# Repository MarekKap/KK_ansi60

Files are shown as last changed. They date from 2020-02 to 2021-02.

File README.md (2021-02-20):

# KK_ansi60
60% mechanical keyboard

KK_ansi60 keyboard is inspired by [GH60 open source keyboard](https://github.com/komar007/gh60).
Case and mounting plate are made from one piece of aluminium alloy. This feature allows very
solid and compact design. On the other hand only ane switch layout is supported.
Keyboard support TMK firmware, so everything is open source and customizable. On default there
are two base layers. Active layer is indicated with LED under FN1 or FN2 key.

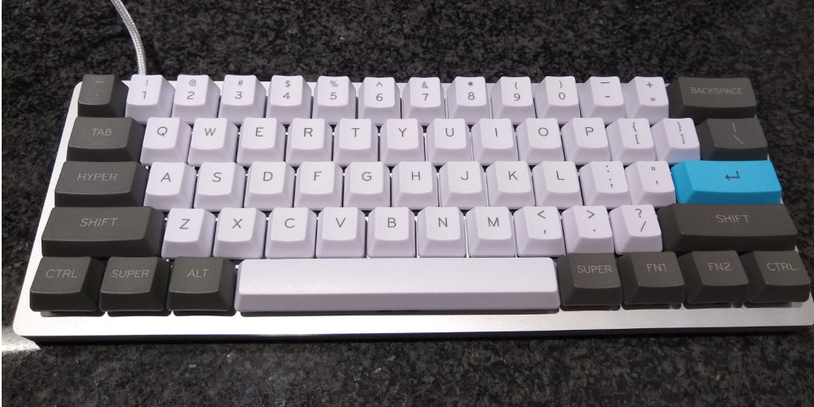
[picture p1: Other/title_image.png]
title image


## Build instructions
1. Solder all SMDs parts on PCB.
2. Temporary solder USB cable on connector `J1`.
3. Load firmware.
   1. Plug USB cable into computer.
   2. Run command `dmesg`, you should see `Product: ATm32U4DFU` in output list. If not,
      double check your soldering and check if you have ATMEGA32u4 with DFU bootloader.
   3. Clone repo `git clone "https://github.com/MarekKap/KK_ansi60"`.
   4. Go to firmware directory `cd KK_ansi60/Firmware/`.
   5. Compile program `make`.
   6. Load firmware into keyboard `sudo make dfu`.
   7. Unplug USB cable from computer.
4. Desolder USB cable.
5. Install keycaps stabilizers on top plate.
6. Install some switchies on on top plate. Start with edges and long keys.
7. Flip the top plate and put PCB on installed switches.
8. Cut switch legs. Keep in mind, there is only 2mm space between PCB and bottom plate.
9. Solder switches on PCB.
10. Install, cut and solder rest of the switches.
11. Install, cut and solder `LED1` and `LED2`.
12. Remove insulation from USB cable. Use heat shring tube or your nylon cable sleeve will
    start stripping over time.
13. Use cable tie to hold USB cable in place.
14. Solder free USB wires to connector `J1`. Keep `D+` and `D-` wires twisted as long as
    possible.
15. Hold down USB wires using kapton tape on PCB.
16. Install CNC legs with screws on bottom plate and put self adhesive pads in place.
17. Stick a insulation sticker on bottom plate (PCB side).
18. Screw bootom and top piece together with M2.5 screws.
19. Plug USB cable into computer and enjoy your keyboard. :-)

## Where to buy
| Item | Seller | Price [EUR] | Note |
| --- | --- | --- | --- |
| Resistor 22R (R1, R2) | [Farnell][1] | 0.09 | for 10 pcs |
| Resistor 10K (R3, R4) | [Farnell][2] | 0.09 | for 10 pcs |
| Resistor 82R (R5, R6) | [Farnell][3] | 0.13 | for 10 pcs |
| Capacitor 10uF (C1) | [Farnell][4] | 0.80 | for 5 pcs |
| Capacitor 0.1uF (C2-C6, C8) | [Farnell][5] | 0.52 | for 10 pcs |
| Capacitor 1uF (C7) | [Farnell][6] | 1.33 | for 5 pcs |
| Capacitor 22pF (C9, C10) | [Farnell][7] | 1.23 | for 10 pcs |
| White LED (LED1, LED2) | [Farnell][8] | 2.54 | for 5 pcs |
| Quartz 16MHz (Y1) | [Farnell][9] or [Farnell][18]| 0.84 | |
| ATMEGA32u4 (U1) | [Farnell][10] | 3.71 | |
| Diode TS148 (D1-D61) | [Farnell][11] | 5.23 | |
| Switch (S1-S61) | [AliExpress][12] | 18.04 | 3 pin 65 pcs |
| PCB | KK-electronic | 25.00 | work in progress |
| Stabilizers set | [AliExpress][13] | 7.20 | 6.25u plate mounted |
| USB cable | Any local store | 3.00 | |
| Top Plate | KK-electronic | 120.00 | work in progress |
| Bottom Plate | KK-electronic | 40.00 | work in progress |
| CNC Legs | [AliExpress][15] | 3.00 | silver |
| Self adhesive pads | [AliExpress][16] | 11.00 | for 500 pcs |
| Insulation sticker | KK-electronic | 10.00 | work in progress |
| Keycap set | [AliExpress][17] | 21.00 | |

> If you are intrested in KK-electronic parts, please email at <kaplan.marek@gmail.com>.
> Price is approx. and can by significantly lower on group buy.

[1]: https://sk.farnell.com/multicomp/mcwr08x22r0ftl/res-22r-1-0-125w-0805-thick-film/dp/2447609
[2]: https://sk.farnell.com/multicomp/mcwr08x1002ftl/res-10k-1-0-125w-0805-thick-film/dp/2447553
[3]: https://sk.farnell.com/multicomp/mcmr08x820-jtl/res-82r-5-0-125w-0805-ceramic/dp/2073848
[4]: https://sk.farnell.com/kemet/c0805c106k8pactu/cap-10-f-10v-10-x5r-0805/dp/1463362 
[5]: https://sk.farnell.com/multicomp/mc0805b104m500ct/cap-0-1-f-50v-20-x7r-0805/dp/2627477
[6]: https://sk.farnell.com/multicomp/mc0805f105z500ct/cap-1-f-50v-y5v-0805/dp/1759432
[7]: https://sk.farnell.com/multicomp/mca0805c220jct/cap-22pf-100v-5-c0g-np0-0805/dp/9406247
[8]: https://sk.farnell.com/multicomp/mcl034swc-wh1/led-3mm-36-pure-white/dp/1581176
[9]: https://sk.farnell.com/qantek-technology-corporation/qc3216-0000f12b12m/crystal-16mhz-12pf-3-2mm-x-2-5mm/dp/2508646
[10]: https://sk.farnell.com/microchip/atmega32u4-au/mcu-8bit-megaavr-16mhz-tqfp-44/dp/1748525
[11]: https://sk.farnell.com/taiwan-semiconductor/ts4148-ryg/diode-small-signal-75v-0-15a-0805/dp/2708389
[12]: https://www.aliexpress.com/item/32797603005.html
[13]: https://www.aliexpress.com/item/32800781632.html
[15]: https://www.aliexpress.com/item/4000786300405.html
[16]: https://www.aliexpress.com/item/32242384655.html
[17]: https://www.aliexpress.com/item/32839583006.html
[18]: https://sk.farnell.com/multicomp/mcsjk-7u-16-00-12-30-80-b-30/crystal-16mhz-12pf-3-2mm-x-2-5mm/dp/2853937

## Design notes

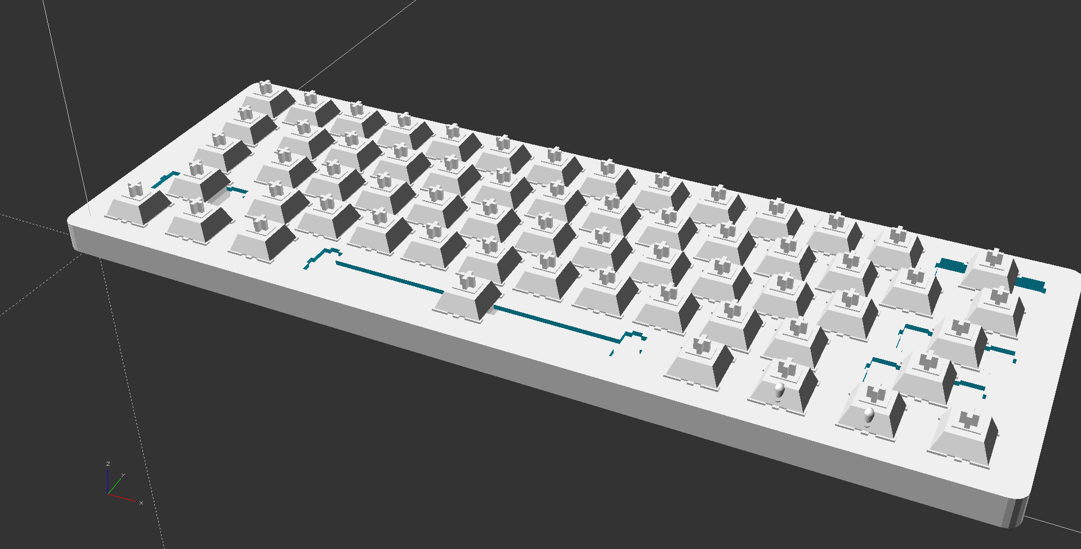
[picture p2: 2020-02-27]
Other/KK_ansi60_3d_no_keycaps.png

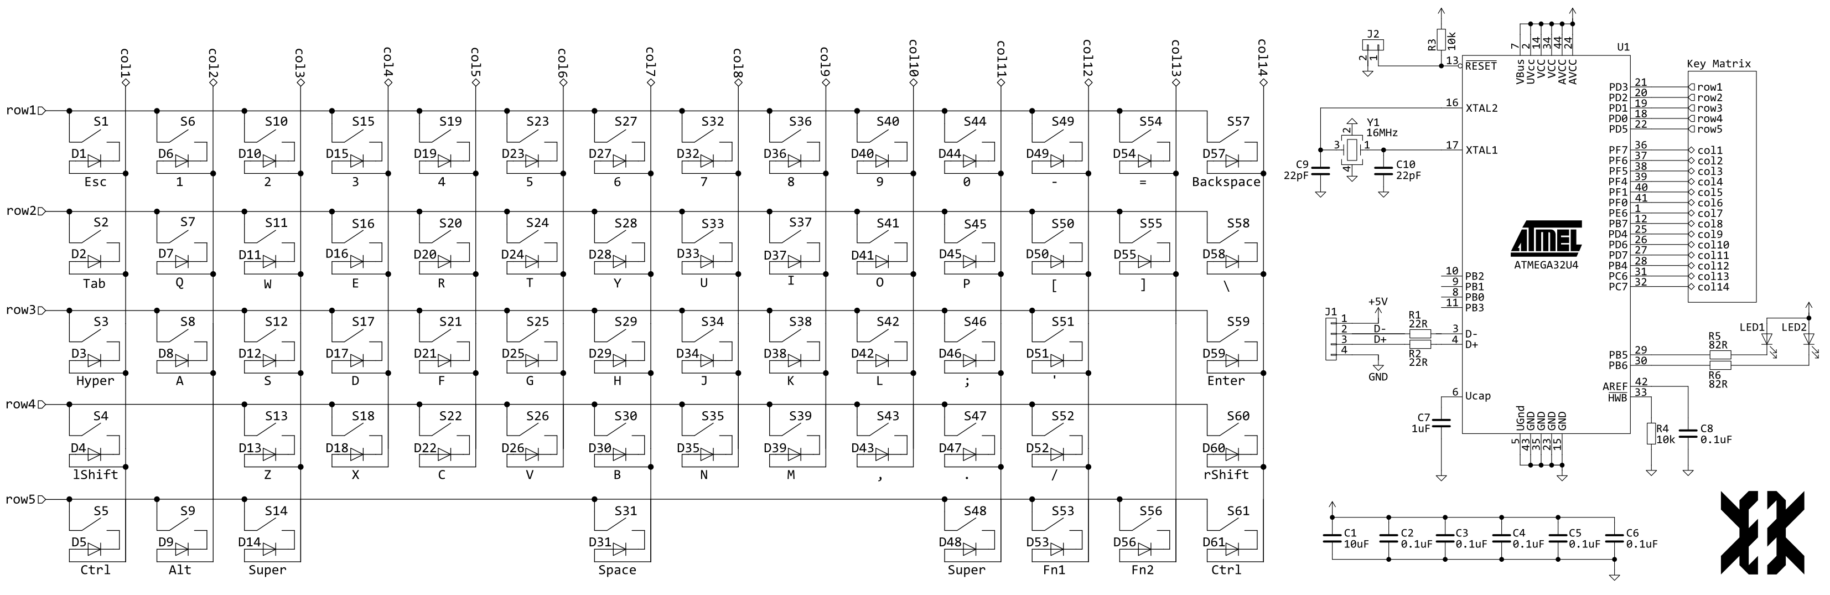
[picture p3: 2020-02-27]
Other/isolation_sticker.png

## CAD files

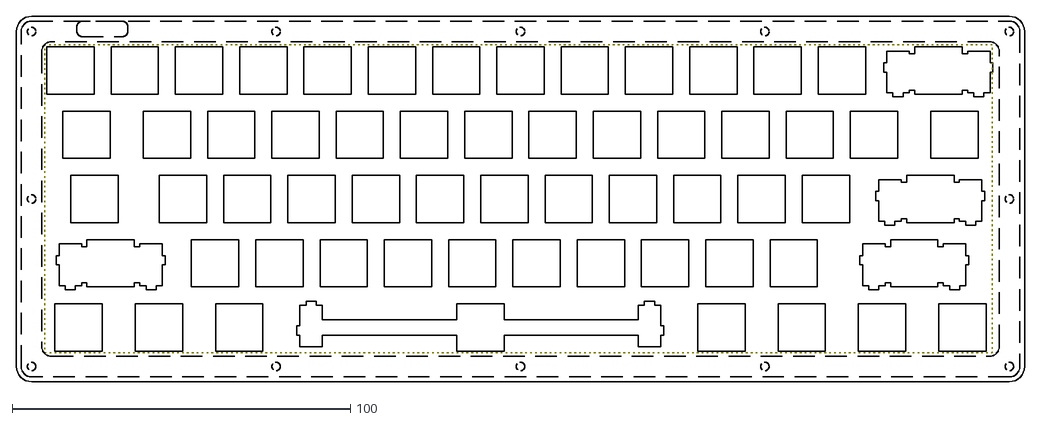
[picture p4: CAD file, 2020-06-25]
Mechanical/KK_ANSI60_top.dxf
298.0 x 108.0

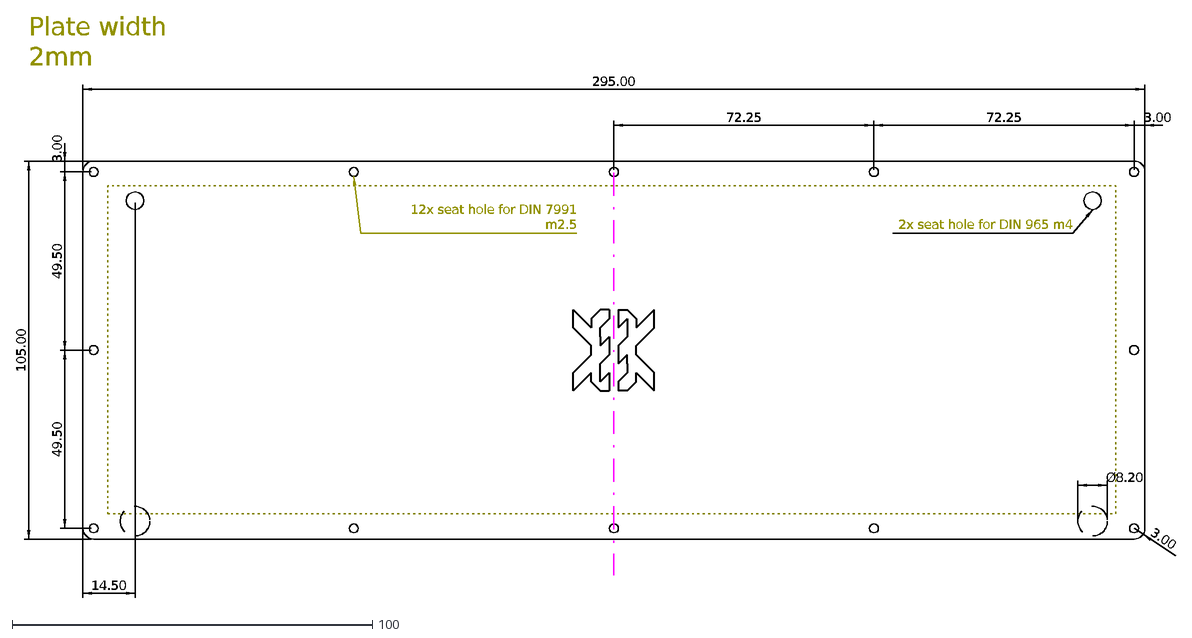
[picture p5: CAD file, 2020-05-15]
Mechanical/KK_ANSI60_bottom.dxf
105.00
295.00
3.00
Plate width 2mm
2x seat hole for DIN 965 m4
Ø8.20
14.50
12x seat hole for DIN 7991 m2.5
49.50
72.25

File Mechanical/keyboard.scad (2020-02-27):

max_height = 10;

module leg()
{
    difference()
    {
        union()
        {
            cylinder(4,11,11);
            translate([0,0,4])cylinder(6,11,5);
        }
        translate([0,0,8])cylinder(3,4,4);
        translate([0,0,-1])cylinder(5,2,2);
    }
}
// top plate
difference()
{
    // base shape
    linear_extrude(height = max_height, center = false, convexity = 10)
        import (file = "KK_ANSI60_top.dxf", layer = "out_line");   
    // switch cutouts
    translate([0,0,-0.5])
        linear_extrude(height = max_height+1, center = false, convexity = 10)
            import (file = "KK_ANSI60_top.dxf", layer = "cut_true");    
    // 8.5mm pocket
    translate([0,0,-0.5])
        linear_extrude(height = 8.6+0.5, center = false, convexity = 10)
            import (file = "KK_ANSI60_top.dxf", layer = "pocket_8.6mm");   
    // 2mm pocket
    translate([0,0,-0.5])
        linear_extrude(height = 2+0.5, center = false, convexity = 10)
            import (file = "KK_ANSI60_top.dxf", layer = "pocket_2mm"); 
    // m2.5 threats
    translate([0,0,-0.5])
        linear_extrude(height = max_height-1.5+0.5, center = false, convexity = 10, $fn = 10)
            import (file = "KK_ANSI60_top.dxf", layer = "M2.5_1.5mm");
}

// bottom plate
difference()
{
    //base shape
    linear_extrude(height = 2, center = false, convexity = 10)
        import (file = "KK_ANSI60_bottom.dxf", layer = "out_line");
    //cutouts
    translate([0,0,-0.5])
        linear_extrude(height = 2+1, center = false, convexity = 10, $fn = 10)
            import (file = "KK_ANSI60_bottom.dxf", layer = "cut_true");
    //adesive legs place
    translate([0,0,-0.5])
        linear_extrude(height = 0.5+0.5, center = false, convexity = 10)
            import (file = "KK_ANSI60_bottom.dxf", layer = "pocket_-0.5mm");
}

//legs
translate([9.5,89,0])mirror([0,0,1])leg();
translate([275.5,89,0])mirror([0,0,1])leg();

//PCB
translate([1.9,2.1,4])
    import(file = "KK_ANSI60_PCB.stl");

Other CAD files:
Mechanical/KK_ANSI60_top_drawing.dxf

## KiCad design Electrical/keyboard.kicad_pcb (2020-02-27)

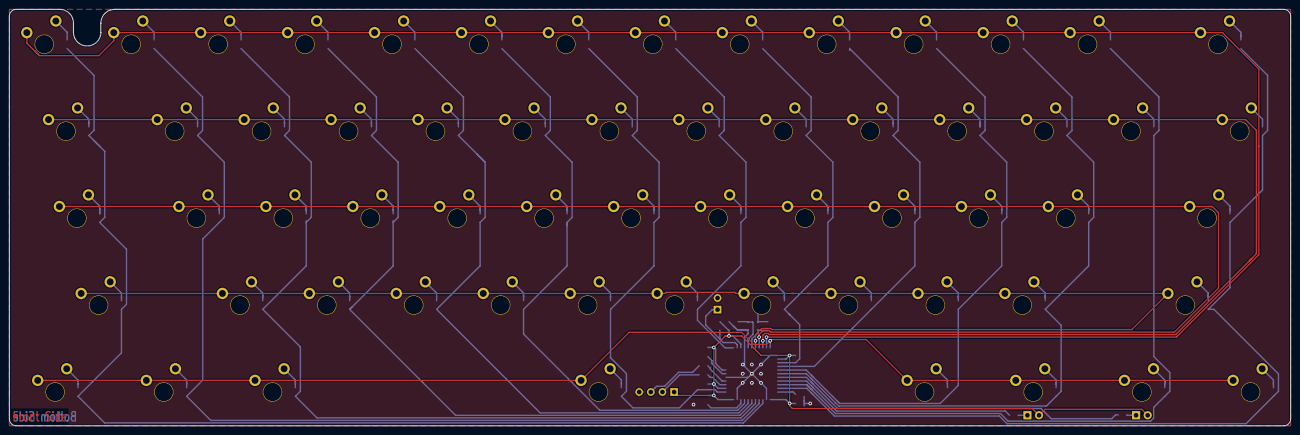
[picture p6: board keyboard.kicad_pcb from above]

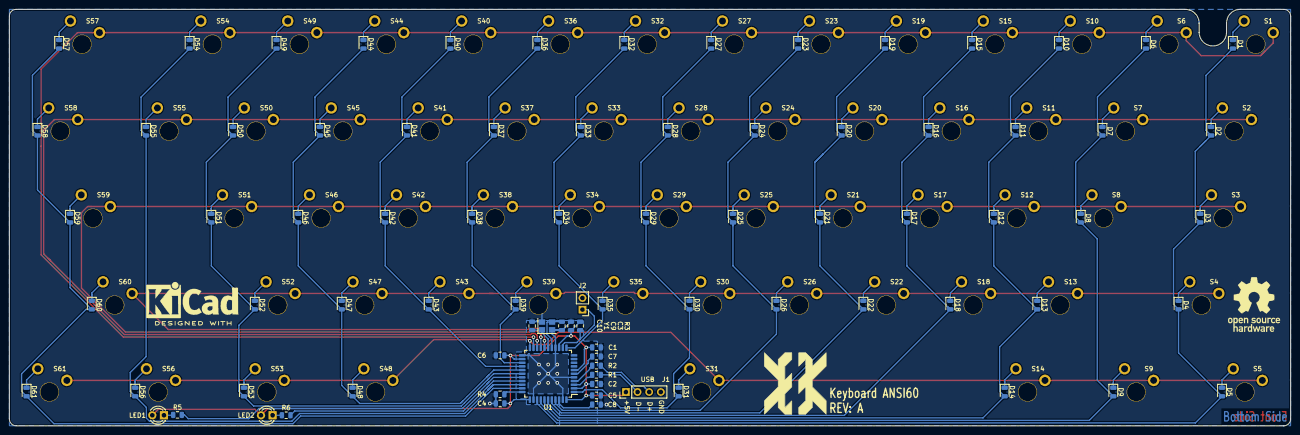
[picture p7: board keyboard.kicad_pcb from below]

Board: 2 copper layers, 280.0 x 91.0 mm, 144 parts (81 on the bottom side), 96 nets.

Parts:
C1: 10uF; C_0805_2012Metric
C2, C3, C4, C5, C6, C8: 0.1uF; C_0805_2012Metric
C7: 1uF; C_0805_2012Metric
C9, C10: 22pF; C_0805_2012Metric
D1, D2, D3, D4, D5, D6, D7, D8, D9, D10, D11, D12, D13, D14, D15, D16, D17, D18, D19, D20, D21, D22, D23, D24, D25, D26, D27, D28, D29, D30, D31, D32, D33, D34, D35, D36, D37, D38, D39, D40, D41, D42, D43, D44, D45, D46, D47, D48, D49, D50, D51, D52, D53, D54, D55, D56, D57, D58, D59, D60, D61: TS4148; D_0805_2012Metric
J1: USB; PinHeader_1x04_P2.54mm_Vertical
J2: Conn_01x02; PinHeader_1x02_P2.54mm_Vertical
LED1, LED2: White; LED_D3.0mm_Clear
R1, R2: 22; R_0805_2012Metric
R3, R4: 10k; R_0805_2012Metric
R5, R6: 82; R_0805_2012Metric
S1, S2, S3, S4, S5, S6, S7, S8, S9, S10, S11, S12, S13, S14, S15, S16, S17, S18, S19, S20, S21, S22, S23, S24, S25, S26, S27, S28, S29, S30, S31, S32, S33, S34, S35, S36, S37, S38, S39, S40, S41, S42, S43, S44, S45, S46, S47, S48, S49, S50, S51, S52, S53, S54, S55, S56, S57, S58, S59, S60, S61: MX1A; MX1A-plate
U1: ATMEGA32U4; LQFP-44_10x10mm_P0.8mm
Y1: 16MHz; Crystal_SMD_3225-4Pin_3.2x2.5mm

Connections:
+5V: C1.1, C2.1, C3.1, C4.1, C5.1, C6.1, J1.1, LED1.2, LED2.2, R3.2, U1.2, U1.7, U1.14, U1.24, U1.34, U1.44
/D+: J1.3, R2.1
/D-: J1.2, R1.2
/Matrix/col1: D1.2, D2.2, D3.2, D4.2, D5.2, U1.36
/Matrix/col2: D6.2, D7.2, D8.2, D9.2, U1.37
/Matrix/col3: D10.2, D11.2, D12.2, D13.2, D14.2, U1.38
/Matrix/col4: D15.2, D16.2, D17.2, D18.2, U1.39
/Matrix/col5: D19.2, D20.2, D21.2, D22.2, U1.40
/Matrix/col6: D23.2, D24.2, D25.2, D26.2, U1.41
/Matrix/col7: D27.2, D28.2, D29.2, D30.2, D31.2, U1.1
/Matrix/col8: D32.2, D33.2, D34.2, D35.2, U1.12
/Matrix/col9: D36.2, D37.2, D38.2, D39.2, U1.25
/Matrix/col10: D40.2, D41.2, D42.2, D43.2, U1.26
/Matrix/col11: D44.2, D45.2, D46.2, D47.2, D48.2, U1.27
/Matrix/col12: D49.2, D50.2, D51.2, D52.2, D53.2, U1.28
/Matrix/col13: D54.2, D55.2, D56.2, U1.31
/Matrix/col14: D57.2, D58.2, D59.2, D60.2, D61.2, U1.32
/Matrix/row1: S1.1, S6.1, S10.1, S15.1, S19.1, S23.1, S27.1, S32.1, S36.1, S40.1, S44.1, S49.1, S54.1, S57.1, U1.21
/Matrix/row2: S2.1, S7.1, S11.1, S16.1, S20.1, S24.1, S28.1, S33.1, S37.1, S41.1, S45.1, S50.1, S55.1, S58.1, U1.20
/Matrix/row3: S3.1, S8.1, S12.1, S17.1, S21.1, S25.1, S29.1, S34.1, S38.1, S42.1, S46.1, S51.1, S59.1, U1.19
/Matrix/row4: S4.1, S13.1, S18.1, S22.1, S26.1, S30.1, S35.1, S39.1, S43.1, S47.1, S52.1, S60.1, U1.18
/Matrix/row5: S5.1, S9.1, S14.1, S31.1, S48.1, S53.1, S56.1, S61.1, U1.22
GND: C1.2, C2.2, C3.2, C4.2, C5.2, C6.2, C7.2, C8.2, C9.1, C10.1, J1.4, J2.2, R4.2, U1.5, U1.15, U1.23, U1.35, U1.43, Y1.2, Y1.4
unnamed: C7.1, U1.6
unnamed: C8.1, U1.42
unnamed: C9.2, U1.16, Y1.3
unnamed: C10.2, U1.17, Y1.1
unnamed: D1.1, S1.2
unnamed: D2.1, S2.2
unnamed: D3.1, S3.2
unnamed: D4.1, S4.2
unnamed: D5.1, S5.2
unnamed: D6.1, S6.2
unnamed: D7.1, S7.2
unnamed: D8.1, S8.2
unnamed: D9.1, S9.2
unnamed: D10.1, S10.2
unnamed: D11.1, S11.2
unnamed: D12.1, S12.2
unnamed: D13.1, S13.2
unnamed: D14.1, S14.2
unnamed: D15.1, S15.2
unnamed: D16.1, S16.2
unnamed: D17.1, S17.2
unnamed: D18.1, S18.2
unnamed: D19.1, S19.2
unnamed: D20.1, S20.2
unnamed: D21.1, S21.2
unnamed: D22.1, S22.2
unnamed: D23.1, S23.2
unnamed: D24.1, S24.2
unnamed: D25.1, S25.2
unnamed: D26.1, S26.2
unnamed: D27.1, S27.2
unnamed: D28.1, S28.2
unnamed: D29.1, S29.2
unnamed: D30.1, S30.2
unnamed: D31.1, S31.2
unnamed: D32.1, S32.2
unnamed: D33.1, S33.2
unnamed: D34.1, S34.2
unnamed: D35.1, S35.2
unnamed: D36.1, S36.2
unnamed: D37.1, S37.2
unnamed: D38.1, S38.2
unnamed: D39.1, S39.2
unnamed: D40.1, S40.2
unnamed: D41.1, S41.2
unnamed: D42.1, S42.2
unnamed: D43.1, S43.2
unnamed: D44.1, S44.2
unnamed: D45.1, S45.2
unnamed: D46.1, S46.2
unnamed: D47.1, S47.2
unnamed: D48.1, S48.2
unnamed: D49.1, S49.2
unnamed: D50.1, S50.2
unnamed: D51.1, S51.2
unnamed: D52.1, S52.2
unnamed: D53.1, S53.2
unnamed: D54.1, S54.2
unnamed: D55.1, S55.2
unnamed: D56.1, S56.2
unnamed: D57.1, S57.2
unnamed: D58.1, S58.2
unnamed: D59.1, S59.2
unnamed: D60.1, S60.2
unnamed: D61.1, S61.2
unnamed: J2.1, R3.1, U1.13
unnamed: LED1.1, R5.1
unnamed: LED2.1, R6.1
unnamed: R1.1, U1.3
unnamed: R2.2, U1.4
unnamed: R4.1, U1.33
unnamed: R5.2, U1.29
unnamed: R6.2, U1.30

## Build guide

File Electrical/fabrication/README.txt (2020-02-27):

keyboard-PTH.drl - EXCELLON pokovene diery
keyboard-B_Cu.gbr - GERBER RS274-X zadna medena vrstva pohlad zo strany suciastok
keyboard-B_Mask.gbr - GERBER RS274-X zadna nepajiva maska pohlad zo strany suciastok
keyboard-B_SilkS.gbr - GERBER RS274-X popisky predna vrstva pohlad zo strany suciastok
keyboard-Edge_Cuts.gbr - GERBER RS274-X rezne hrany pohlad zo strany suciastok
keyboard-F_Cu.gbr - GERBER RS274-X predna medena vrstva pohlad zo strany suciastok
keyboard-F_Mask.gbr - GERBER RS274-X predna nepajiva maska pohlad zo strany suciastok

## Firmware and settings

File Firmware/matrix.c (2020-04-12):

/*
Copyright 2012 Jun Wako <wakojun@gmail.com>

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
You should have received a copy of the GNU General Public License
along with this program.  If not, see <http://www.gnu.org/licenses/>.
*/

/*
 * scan matrix
 */
#include <stdint.h>
#include <stdbool.h>
#include <avr/io.h>
#include <util/delay.h>
#include "print.h"
#include "debug.h"
#include "util.h"
#include "matrix.h"


#ifndef DEBOUNCE
#   define DEBOUNCE	5
#endif
static uint8_t debouncing = DEBOUNCE;

/* matrix state(1:on, 0:off) */
static matrix_row_t matrix[MATRIX_ROWS];
static matrix_row_t matrix_debouncing[MATRIX_ROWS];

static matrix_row_t read_cols(void);
static void init_cols(void);
static void unselect_rows(void);
static void select_row(uint8_t row);


void matrix_init(void)
{
    // initialize row and col
    unselect_rows();
    init_cols();

    // initialize matrix state: all keys off
    for (uint8_t i=0; i < MATRIX_ROWS; i++) {
        matrix[i] = 0;
        matrix_debouncing[i] = 0;
    }
}

uint8_t matrix_scan(void)
{
    for (uint8_t i = 0; i < MATRIX_ROWS; i++) {
        select_row(i);
        _delay_us(30);  // without this wait read unstable value.
        matrix_row_t cols = read_cols();
        if (matrix_debouncing[i] != cols) {
            matrix_debouncing[i] = cols;
            if (debouncing) {
                debug("bounce!: "); debug_hex(debouncing); debug("\n");
            }
            debouncing = DEBOUNCE;
        }
        unselect_rows();
    }

    if (debouncing) {
        if (--debouncing) {
            _delay_ms(1);
        } else {
            for (uint8_t i = 0; i < MATRIX_ROWS; i++) {
                matrix[i] = matrix_debouncing[i];
            }
        }
    }

    return 1;
}

inline
matrix_row_t matrix_get_row(uint8_t row)
{
    return matrix[row];
}

static void init_cols(void) {
  // Must disable JTAG to use PORTF pins as GPIO
  MCUCR = (1<<JTD);
  MCUCR = (1<<JTD);
  // Input with pull-up(DDR:0, PORT:1)
  DDRF  &= ~(1<<PF7 | 1<<PF6 | 1<<PF5 | 1<<PF4 | 1<<PF1 | 1<<PF0);
  PORTF |=  (1<<PF7 | 1<<PF6 | 1<<PF5 | 1<<PF4 | 1<<PF1 | 1<<PF0);
  DDRE  &= ~(1<<PE6);
  PORTE |=  (1<<PE6);
  DDRD  &= ~(1<<PD7 | 1<<PD6 | 1<<PD4);
  PORTD |=  (1<<PD7 | 1<<PD6 | 1<<PD4);
  DDRC  &= ~(1<<PC7 | 1<<PC6);
  PORTC |=  (1<<PC7 | 1<<PC6);
  DDRB  &= ~(1<<PB7 | 1<<PB4);
  PORTB |=  (1<<PB7 | 1<<PB4);
}

static matrix_row_t read_cols(void) {
  return
    (PINF&(1<<PF7) ? 0 : (1<<0)) |
    (PINF&(1<<PF6) ? 0 : (1<<1)) |
    (PINF&(1<<PF5) ? 0 : (1<<2)) |
    (PINF&(1<<PF4) ? 0 : (1<<3)) |
    (PINF&(1<<PF1) ? 0 : (1<<4)) |
    (PINF&(1<<PF0) ? 0 : (1<<5)) |
    (PINE&(1<<PE6) ? 0 : (1<<6)) |
    (PINB&(1<<PB7) ? 0 : (1<<7)) |
    (PIND&(1<<PD4) ? 0 : (1<<8)) |
    (PIND&(1<<PD6) ? 0 : (1<<9)) |
    (PIND&(1<<PD7) ? 0 : (1<<10)) |
    (PINB&(1<<PB4) ? 0 : (1<<11)) |
    (PINC&(1<<PC6) ? 0 : (1<<12)) |
    (PINC&(1<<PC7) ? 0 : (1<<13));
}

/* Row pin configuration
 * row: 0   1   2   3   4
 * pin: D3  D2  D1  D0  D5
 */
static void select_row(uint8_t row) {
  // Output low(DDR:1, PORT:0) to select
  switch (row) {
    case 0:
      DDRD  |= (1<<PD3);
      PORTD &= ~(1<<PD3);
      break;
    case 1:
      DDRD  |= (1<<PD2);
      PORTD &= ~(1<<PD2);
      break;
    case 2:
      DDRD  |= (1<<PD1);
      PORTD &= ~(1<<PD1);
      break;
    case 3:
      DDRD  |= (1<<PD0);
      PORTD &= ~(1<<PD0);
      break;
    case 4:
      DDRD  |= (1<<PD5);
      PORTD &= ~(1<<PD5);
      break;
  }
}

static void unselect_rows(void)
{
    // Hi-Z(DDR:0, PORT:0) to unselect
    DDRD  &= ~0b00101111;
    PORTD &= ~0b00101111;
}

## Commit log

2020-02-27 new file: Electrical/doc/1n4148w.pdf new file: Electrical/doc/MX Series.pdf new file: Electrical/doc/QC32 SMD crystal.pdf new file: Electrical/doc/RoundLED.pdf new file: Electrical/doc/TS4148.pdf new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
    [BOM.ods, KK_ANSI60_bottom.dxf, KK_ANSI60_top.dxf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]
2020-02-27 deleted: Other/Electrical/BOM.ods deleted: Other/Electrical/doc/1n4148w.pdf deleted: Other/Electrical/doc/MX Series.pdf deleted: Other/Electrical/doc/QC32 SMD crystal.pdf deleted: Other/Electrical/do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
    [BOM.ods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]
2020-02-27 renamed: export/fabrication/README.txt -> fabrication/README.txt renamed: export/fabrication/keyboard-B_Cu.gbr -> fabrication/keyboard-B_Cu.gbr renamed: export/fabrication/keyboard-B_Mask.gbr -> fabr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
    [keyboard-B_Cu.gbr, keyboard-B_Mask.gbr, keyboard-B_SilkS.gbr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]
2020-04-12 led function update
2020-05-15 KK_ANSI60_bottom.dxf update
    [KK_ANSI60_bottom.dxf]
2020-06-25 modified: KK_ANSI60_top.dxf new file: KK_ANSI60_top_drawing.dxf
    [KK_ANSI60_top.dxf, KK_ANSI60_top_drawing.dxf]

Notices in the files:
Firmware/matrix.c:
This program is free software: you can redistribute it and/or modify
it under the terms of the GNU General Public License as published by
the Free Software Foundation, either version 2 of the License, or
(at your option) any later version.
